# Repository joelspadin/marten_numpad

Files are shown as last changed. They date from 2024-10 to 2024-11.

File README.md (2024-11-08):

# Marten Numpad

Marten 22 is a wireless, 21/22 key numpad named after a [cute, woodland animal](https://en.wikipedia.org/wiki/American_marten). (There is no meaning to the name other than that I like them, and I couldn't find any existing keyboards named after them.) It is based on the nRF52840 SoC and uses a 3D printed case.

It has the following features:

- USB and Bluetooth support with [ZMK Firmware](https://zmk.dev/)
- Hot swap sockets for MX switches
- Supports Li-Ion or LiPo batteries up to 68x40x8 mm or 55x44x8 mm.
- The top-left and top-right keys can be replaced with encoders.
  - Supports [SKYLOONG keyboard knobs](https://skyloongtech.com/skyloong-keyboard-knobs/) (silicone/ABS cover versions only) or a separate encoder PCB with 3D printed case
- Any pair of two keys on the top row can be replaced with a display.
  - This uses a separate display PCB and connects with a ribbon cable.
  - nice!view and SSD1306 OLED display modules are supported.

A 22/23 key layout with a split plus key would be possible, but it would require a separate PCB from the 21/22 key layout. There is no way to fit three hot swap sockets into the space for the plus key without rotating the 1U keys 90 degrees, and this could damage keycaps, so I opted not to include that as an option.

(TODO: add renders/pictures of the completed keyboard)

> ⚠️ WARNING ⚠️ </br>
> I have received PCBs but they have not been fully tested. You should probably not make one yourself until I verify that everything works.

**Hardware status:**

| Component | Status |
| --- | --- |
| Numpad PCB | Untested |
| nice!view display module | Untested |
| OLED display module | Untested |
| Encoder module | Untested |
| 3D printed case | Untested |

**Firmware status:**

| Component | Status |
| --- | --- |
| Base firmware | Not implemented |
| Numlock LED | Not implemented |
| Custom display screen | Not implemented |
| nPM1300 charger | Not implemented |
| nPM1300 fuel gauge | Not implemented |
| Power button | Not implemented |

## PCB

KiCad files for the PCBs can be found in the [pcb](./pcb) directory. There are a few PCBs:

- [numpad.kicad_pro](./pcb/numpad.kicad_pro) is the main PCB.
- [display.kicad_pro](./pcb/display.kicad_pro) is an optional daughterboard for connecting a [nice!view](https://nicekeyboards.com/nice-view/) display.
- [display_oled.kicad_pro](./pcb/display_oled.kicad_pro) is an optional daughterboard for connect an SSD1306 OLED display.
  - It works with the common SSD1306 display modules you can find from a wide variety of sellers, but make sure to get one which does _not_ have a pin header already soldered.
- [encoder.kicad_pro](./pcb/encoder.kicad_pro) is an optional daughterboard for an EC11 encoder.
- [peripheral.kicad_pro](./pcb/peripheral.kicad_pro) is template for creating your own daughterboards.

The main PCB requires a couple of parts which are not hand solderable, so PCB assembly is required.

The display and encoder PCBs are hand solderable (though the SMD parts on the encoder are difficult to solder). The encoder PCB also requires modifying the EC11 encoder by clipping its pins short.

Instructions for ordering and assembling the hardware can be found on the wiki.

(TODO: add a wiki page)

[PCBWay](https://www.pcbway.com/) provided me a discount on PCB assembly in exchange for sharing pictures of the completed board and talking about my experience ordering from them. I will add details to the wiki for this once I've finished testing the hardware.

(TODO: add a wiki page)

### Custom Peripherals

The numpad PCB has a [Molex 5051100692](https://www.molex.com/en-us/products/part-detail/5051100692) FFC connector (labeled "Display") which can be used to connect to a daughterboard using a 6-pin ribbon cable. It provides 3.3 V power, two ground pins, and three GPIO pins. While its main purpose is to connect a display, you can use this to add your own custom hardware as well.

(TODO: add a wiki page explaining custom hardware and firmware)

## Case

TODO

## Firmware

TODO

## Credits

- Fonts:
  - [Fredoka](https://fonts.google.com/specimen/Fredoka)
- Libraries:
  - [marbastlib](https://github.com/ebastler/marbastlib)
  - Some footprints are modified from the [KiCad Libraries](https://gitlab.com/kicad/libraries/kicad-footprints)
- 3D models
  - Some 3D models are generated using [KiCad Packages3D Generator](https://gitlab.com/kicad/libraries/kicad-packages3D-generator)
  - [128x32 OLED display](https://grabcad.com/library/0-91-128x32-oled-display-1)
  - [JST SH connector](https://grabcad.com/library/jst-sh-smd-connectors-1)
  - Models for the following parts are provided by their respective manufacturers:
    - [Bourns PEC11L](https://www.bourns.com/products/encoders/contacting-encoders/product/PEC11L)
    - [HRO TYPE-C-31-M-12](https://www.snapeda.com/parts/TYPE-C-31-M-12/HRO%20Electronics%20Co.,%20Ltd./view-part/)
    - [Kingbright APTR3216-VFX](https://www.kingbrightusa.com/product.asp?catalog_name=LED&product_id=APTR3216-VFX)
    - [Molex 781710002](https://www.molex.com/en-us/products/part-detail/781710002)
    - [Molex 5051100692](https://www.molex.com/en-us/products/part-detail/5051100692)
    - [Mill-Max 811-22-002-30-004101](https://www.mill-max.com/products/spring-loaded/pogo-pin-header-strip/811/30-004101/811-22-002-30-004101)
    - [Mill-Max 811-22-004-30-001101](https://www.mill-max.com/products/spring-loaded/pogo-pin-header-strip/811/30-001101/811-22-004-30-001101)
    - [Mill-Max 821-22-005-10-001101](https://www.mill-max.com/products/spring-loaded/pogo-pin-header-strip/821/10-001101/821-22-005-10-001101)
    - [Raytac MDBT50Q-1MV2](https://www.raytac.com/product/ins.php?index_id=24)
    - [Würth 9774005243R](https://www.we-online.com/en/components/products/SMSI_SMT_STEEL_SPACER_M2_THREAD_INTERNAL)

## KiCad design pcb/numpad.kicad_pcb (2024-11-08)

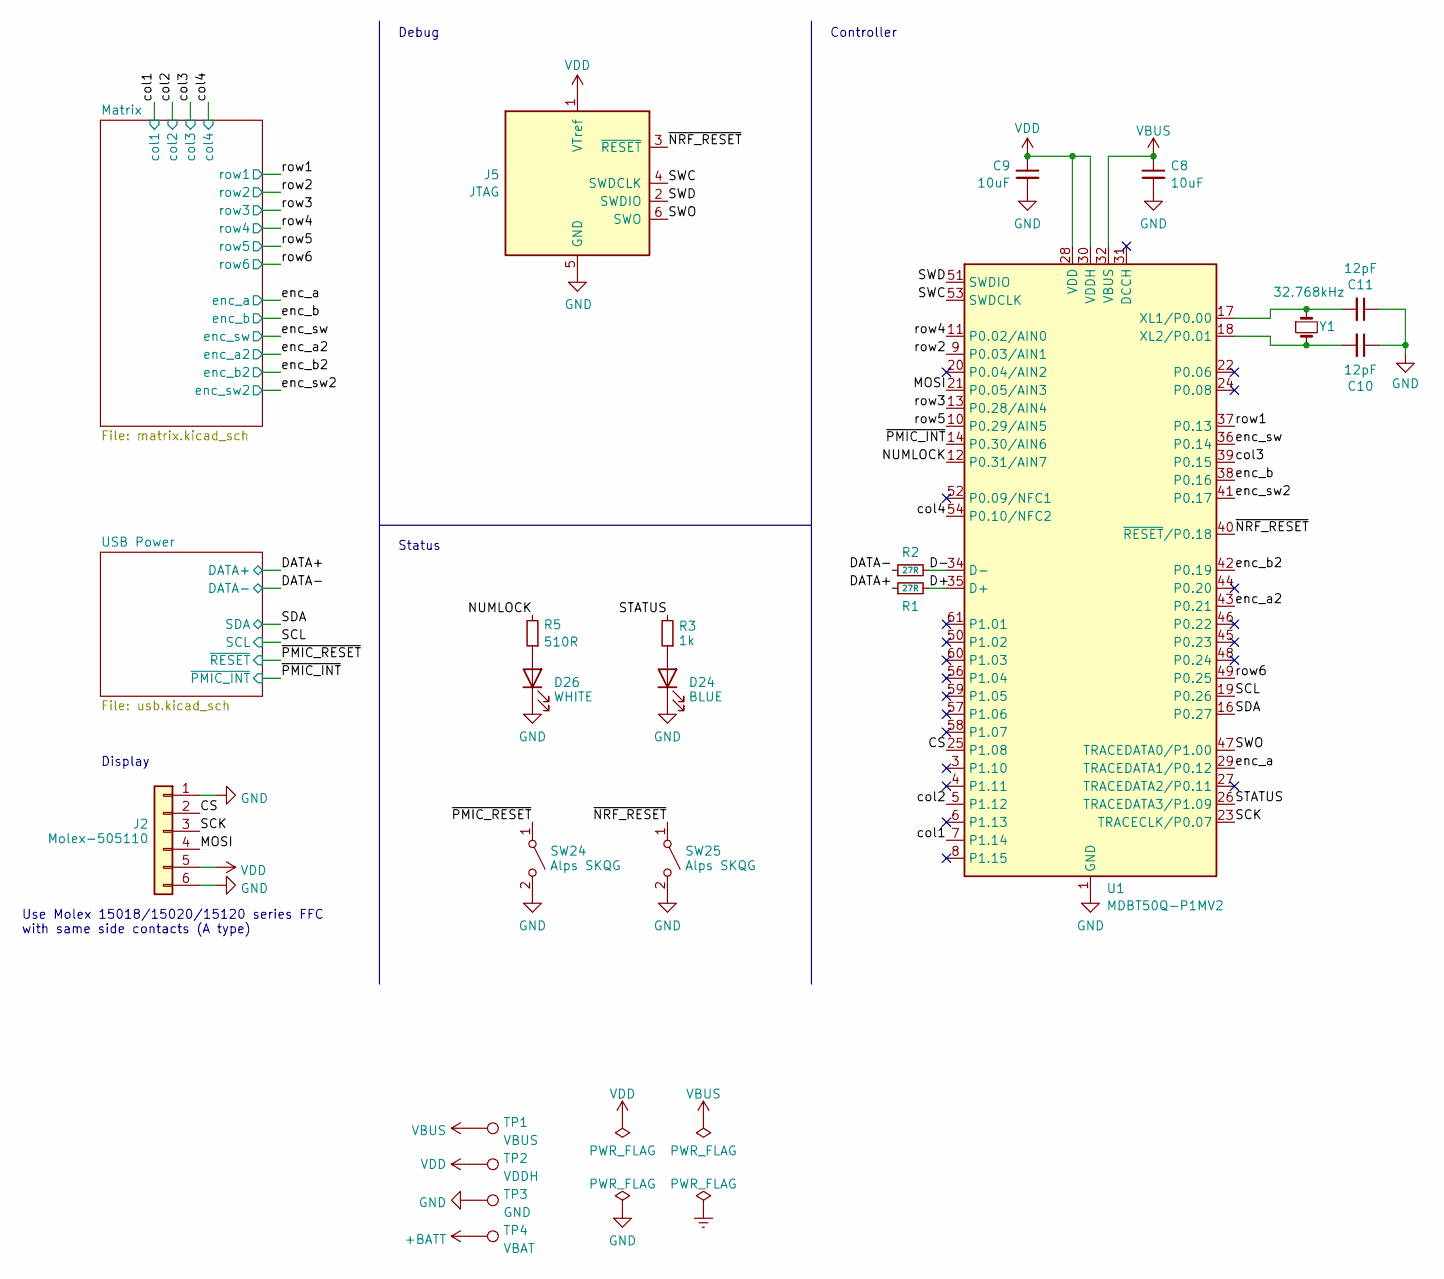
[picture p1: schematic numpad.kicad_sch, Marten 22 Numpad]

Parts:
C8, C9: 10uF; C_0603_1608Metric; Manufacturer Part Number GRM188Z71A106KA73D
C10, C11: 12pF; C_0402_1005Metric; Manufacturer Part Number CC0402GRNPO9BN120
D24: BLUE; LED_0603_1608Metric; Manufacturer Part Number NCD0603B5
D26: WHITE; LED_1206_3216Metric_ReverseMount_Hole2x2mm; Manufacturer Part Number MHT151WDT
J2: Molex-505110; Molex_5051100692_1x06_P0.5mm_Anchor; Manufacturer Part Number 5051100692
J5: JTAG; Tag-Connect_TC2030-IDC-NL_2x03_P1.27mm_Vertical; Manufacturer Part Number DNP
R1, R2: 27R; R_0402_1005Metric; Manufacturer Part Number RC0402FR-0727RL
R3: 1k; R_0603_1608Metric; Manufacturer Part Number FRC0603J102 TS
R5: 510R; R_0603_1608Metric; Manufacturer Part Number FRC0603J471 TS
SW24: Alps SKQG; SW_SPST_SKQG_WithStem; Manufacturer Part Number SKQGADE010
SW25: Alps SKQG; SW_SPST_SKQG_WithStem; Manufacturer Part Number SKQGABE010
TP1: VBUS; TestPoint_Pad_D1.5mm; Manufacturer Part Number DNP
TP2: VDDH; TestPoint_Pad_D1.5mm; Manufacturer Part Number DNP
TP3: GND; TestPoint_Pad_D1.5mm; Manufacturer Part Number DNP
TP4: VBAT; TestPoint_Pad_D1.5mm; Manufacturer Part Number DNP
U1: MDBT50Q-P1MV2; Raytac_MDBT50Q; Manufacturer Part Number MDBT50Q-P1MV2
Y1: 32.768kHz; Crystal_SMD_3215-2Pin_3.2x1.5mm; Manufacturer Part Number SC-32S32.768kHz20PPM9pF

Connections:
+BATT: TP4.1; also elsewhere on the board
/CS: J2.2, U1.25 (P1.08)
/D+: R1.2, U1.35 (D+)
/D-: R2.2, U1.34 (D-)
/DATA+: R1.1; also elsewhere on the board
/DATA-: R2.1; also elsewhere on the board
/MOSI: J2.4, U1.21 (P0.05/AIN3)
/NUMLOCK: R5.2, U1.12 (P0.31/AIN7)
/SCK: J2.3, U1.23 (TRACECLK/P0.07)
/SCL: U1.19 (P0.26); also elsewhere on the board
/SDA: U1.16 (P0.27); also elsewhere on the board
/STATUS: R3.2, U1.26 (TRACEDATA3/P1.09)
/SWC: J5.4 (SWDCLK), U1.53 (SWDCLK)
/SWD: J5.2 (SWDIO), U1.51 (SWDIO)
/SWO: J5.6 (SWO), U1.47 (TRACEDATA0/P1.00)
/col1: U1.7 (P1.14); also elsewhere on the board
/col2: U1.5 (P1.12); also elsewhere on the board
/col3: U1.39 (P0.15); also elsewhere on the board
/col4: U1.54 (P0.10/NFC2); also elsewhere on the board
/enc_a: U1.29 (TRACEDATA1/P0.12); also elsewhere on the board
/enc_a2: U1.43 (P0.21); also elsewhere on the board
/enc_b: U1.38 (P0.16); also elsewhere on the board
/enc_b2: U1.42 (P0.19); also elsewhere on the board
/enc_sw: U1.36 (P0.14); also elsewhere on the board
/enc_sw2: U1.41 (P0.17); also elsewhere on the board
/row1: U1.37 (P0.13); also elsewhere on the board
/row2: U1.9 (P0.03/AIN1); also elsewhere on the board
/row3: U1.13 (P0.28/AIN4); also elsewhere on the board
/row4: U1.11 (P0.02/AIN0); also elsewhere on the board
/row5: U1.10 (P0.29/AIN5); also elsewhere on the board
/row6: U1.49 (P0.25); also elsewhere on the board
/~NRF_RESET: J5.3 (~RESET), SW25.1 (A), U1.40 (~RESET/P0.18)
/~PMIC_INT: U1.14 (P0.30/AIN6); also elsewhere on the board
/~PMIC_RESET: SW24.1 (A); also elsewhere on the board
GND: C8.2, C9.2, C10.1, C11.1, D24.1 (K), D26.1 (K), J2.1, J2.6, J5.5 (GND), SW24.2 (B), SW25.2 (B), TP3.1, U1.1 (GND), U1.2 (GND), U1.15 (GND), U1.33 (GND), U1.55 (GND); also elsewhere on the board
unnamed: D24.2 (A), R3.1
unnamed: D26.2 (A), R5.1
unnamed: C11.2, U1.17 (XL1/P0.00), Y1.1
unnamed: C10.2, U1.18 (XL2/P0.01), Y1.2
VBUS: C8.1, TP1.1, U1.32 (VBUS); also elsewhere on the board
VDD: C9.1, J2.5, J5.1 (VTref), TP2.1, U1.28 (VDD), U1.30 (VDDH); also elsewhere on the board

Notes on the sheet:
Display
Controller
Debug
Use Molex 15018/15020/15120 series FFC with same side contacts (A type)
Status

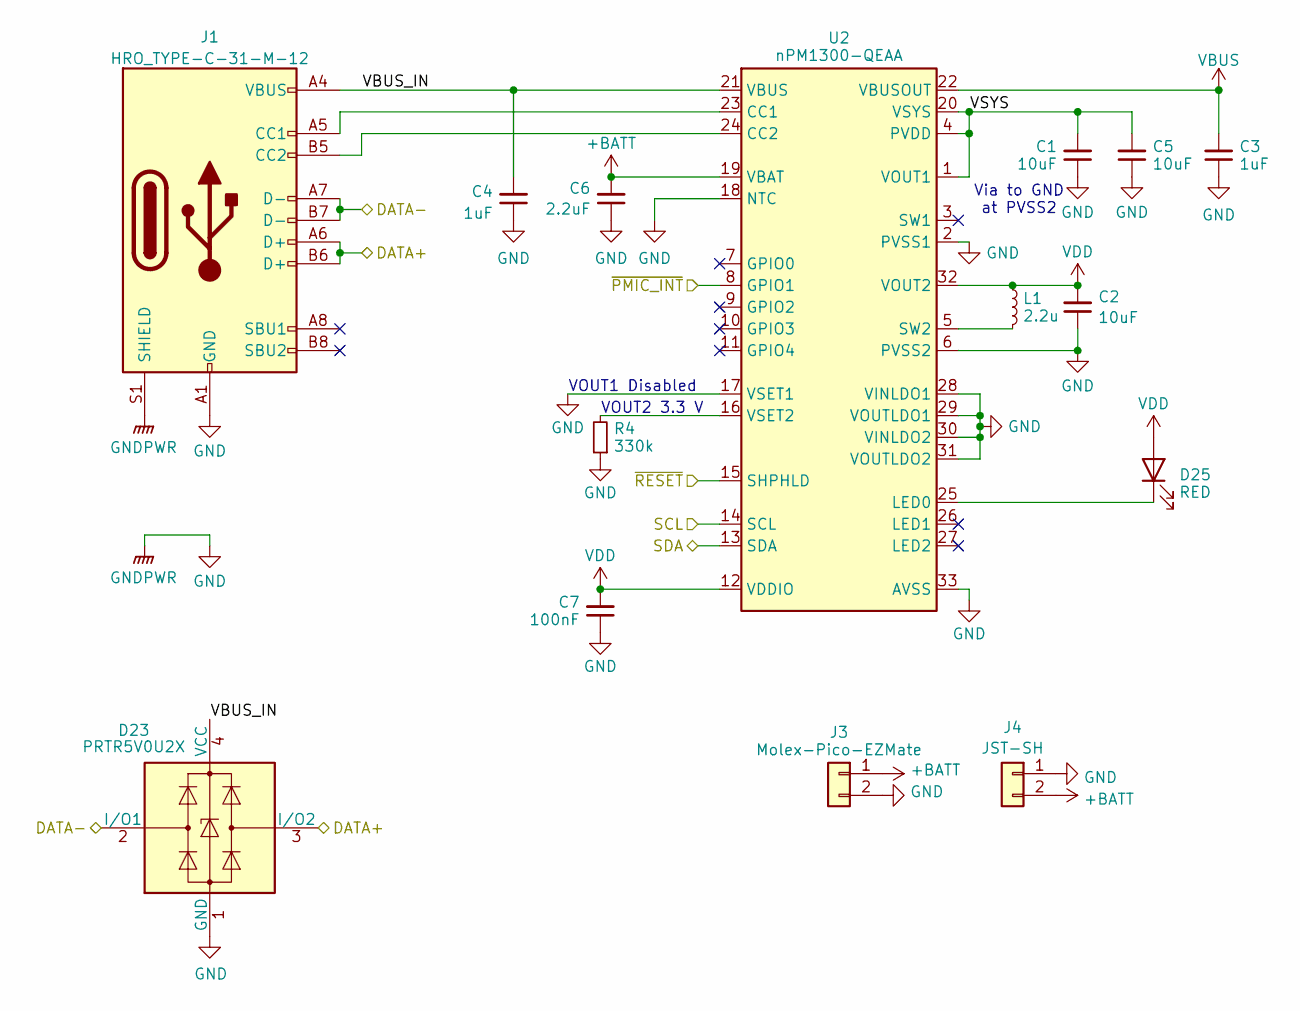
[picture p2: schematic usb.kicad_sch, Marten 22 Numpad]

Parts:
C1, C2, C5: 10uF; C_0603_1608Metric; Manufacturer Part Number 0603X106M250NT
C3, C4: 1uF; C_0603_1608Metric; Manufacturer Part Number 0603X105K100NT
C6: 2.2uF; C_0603_1608Metric; Manufacturer Part Number TCC0603X5R225K250CT
C7: 100nF; C_0402_1005Metric; Manufacturer Part Number TCC0402X5R104K250AT
D23: PRTR5V0U2X; SOT-143; Manufacturer Part Number PRTR5V0U2X,215
D25: RED; LED_0603_1608Metric; Manufacturer Part Number NCD0603R6
J1: HRO_TYPE-C-31-M-12; USB_C_Receptacle_HRO_TYPE-C-31-M-12; Manufacturer Part Number TYPE-C-31-M-12
J3: Molex-Pico-EZMate; Molex_Pico-EZmate_78171-0002_1x02-1MP_P1.20mm_Vertical; Manufacturer Part Number 781710002
J4: JST-SH; JST_SH_SM02B-SRSS-TB_1x02-1MP_P1.00mm_Horizontal_Anchor; Manufacturer Part Number SM02B-SRSS-TB
L1: 2.2u; L_0805_2012Metric; Manufacturer Part Number MLZ2012M2R2HT000
R4: 330k; R_0402_1005Metric; Manufacturer Part Number RC0402FR-07330KL
U2: nPM1300-QEAA; QFN-32-1EP_5x5mm_P0.5mm_EP3.5x3.5mm_ThermalVias; Manufacturer Part Number nPM1300-QEAA

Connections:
+BATT: C6.2, J3.1, J4.2, U2.19 (VBAT); also elsewhere on the board
/DATA+: D23.3 (I/O2), J1.A6 (D+), J1.B6 (D+); also elsewhere on the board
/DATA-: D23.2 (I/O1), J1.A7 (D-), J1.B7 (D-); also elsewhere on the board
/SCL: U2.14 (SCL); also elsewhere on the board
/SDA: U2.13 (SDA); also elsewhere on the board
/USB Power/VBUS_IN: C4.2, D23.4 (VCC), J1.A4 (VBUS), J1.A9 (VBUS), J1.B4 (VBUS), J1.B9 (VBUS), U2.21 (VBUS)
/USB Power/VSYS: C1.2, C5.2, U2.1 (VOUT1), U2.4 (PVDD), U2.20 (VSYS)
/~PMIC_INT: U2.8 (GPIO1); also elsewhere on the board
/~PMIC_RESET: U2.15 (SHPHLD); also elsewhere on the board
GND: C1.1, C2.1, C3.1, C4.1, C5.1, C6.1, C7.1, D23.1 (GND), J1.A1 (GND), J1.A12 (GND), J1.B1 (GND), J1.B12 (GND), J1.S1 (SHIELD), J3.2, J4.1, R4.1, U2.2 (PVSS1), U2.6 (PVSS2), U2.17 (VSET1), U2.18 (NTC), U2.28 (VINLDO1), U2.29 (VOUTLDO1), U2.30 (VINLDO2), U2.31 (VOUTLDO2), U2.33 (AVSS); also elsewhere on the board
unnamed: D25.1 (K), U2.25 (LED0)
unnamed: J1.A5 (CC1), U2.23 (CC1)
unnamed: J1.B5 (CC2), U2.24 (CC2)
unnamed: L1.2, U2.5 (SW2)
unnamed: R4.2, U2.16 (VSET2)
VBUS: C3.2, U2.22 (VBUSOUT); also elsewhere on the board
VDD: C2.2, C7.2, D25.2 (A), L1.1, U2.12 (VDDIO), U2.32 (VOUT2); also elsewhere on the board

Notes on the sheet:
VOUT1 Disabled
Via to GND at PVSS2
VOUT2 3.3 V

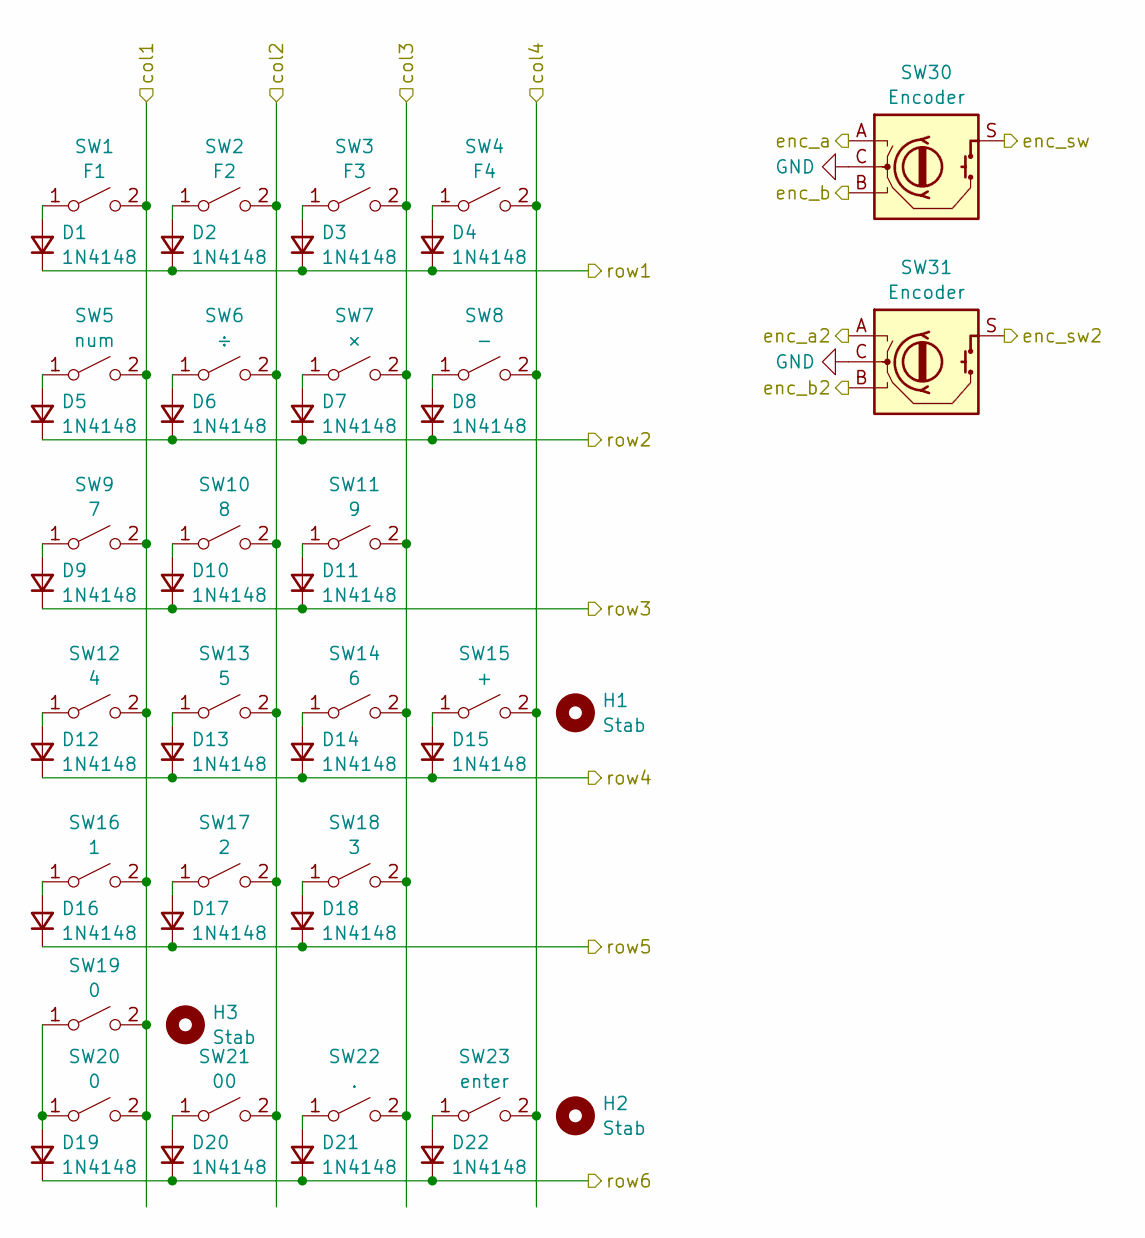
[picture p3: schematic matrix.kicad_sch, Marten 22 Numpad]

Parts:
D1, D2, D3, D4, D5, D6, D7, D8, D9, D10, D11, D12, D13, D14, D15, D16, D17, D18, D19, D20, D21, D22: 1N4148; D_SOD-523; Manufacturer Part Number 1N4148WT
H1, H2, H3: Stab; STAB_MX_2u; Manufacturer Part Number DNP
SW1: F1; SW_MX_HS_CPG151101S11_1u; Manufacturer Part Number CPG151101S11-16
SW2: F2; SW_MX_HS_CPG151101S11_1u; Manufacturer Part Number CPG151101S11-16
SW3: F3; SW_MX_HS_CPG151101S11_1u; Manufacturer Part Number CPG151101S11-16
SW4: F4; SW_MX_HS_CPG151101S11_1u; Manufacturer Part Number CPG151101S11-16
SW5: num; SW_MX_HS_CPG151101S11_1u; Manufacturer Part Number CPG151101S11-16
SW6: ÷; SW_MX_HS_CPG151101S11_1u; Manufacturer Part Number CPG151101S11-16
SW7: ×; SW_MX_HS_CPG151101S11_1u; Manufacturer Part Number CPG151101S11-16
SW8: −; SW_MX_HS_CPG151101S11_1u; Manufacturer Part Number CPG151101S11-16
SW9: 7; SW_MX_HS_CPG151101S11_1u; Manufacturer Part Number CPG151101S11-16
SW10: 8; SW_MX_HS_CPG151101S11_1u; Manufacturer Part Number CPG151101S11-16
SW11: 9; SW_MX_HS_CPG151101S11_1u; Manufacturer Part Number CPG151101S11-16
SW12: 4; SW_MX_HS_CPG151101S11_1u; Manufacturer Part Number CPG151101S11-16
SW13: 5; SW_MX_HS_CPG151101S11_1u; Manufacturer Part Number CPG151101S11-16
SW14: 6; SW_MX_HS_CPG151101S11_1u; Manufacturer Part Number CPG151101S11-16
SW15: +; SW_MX_HS_CPG151101S11_1u; Manufacturer Part Number CPG151101S11-16
SW16: 1; SW_MX_HS_CPG151101S11_1u; Manufacturer Part Number CPG151101S11-16
SW17: 2; SW_MX_HS_CPG151101S11_1u; Manufacturer Part Number CPG151101S11-16
SW18: 3; SW_MX_HS_CPG151101S11_1u; Manufacturer Part Number CPG151101S11-16
SW19, SW20: 0; SW_MX_HS_CPG151101S11_1u; Manufacturer Part Number CPG151101S11-16
SW21: 00; SW_MX_HS_CPG151101S11_1u; Manufacturer Part Number CPG151101S11-16
SW22: .; SW_MX_HS_CPG151101S11_1u; Manufacturer Part Number CPG151101S11-16
SW23: enter; SW_MX_HS_CPG151101S11_1u; Manufacturer Part Number CPG151101S11-16
SW30, SW31: Encoder; Skyloong_Knob_Pads; Manufacturer Part Number DNP

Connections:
/col1: SW1.2 (B), SW5.2 (B), SW9.2 (B), SW12.2 (B), SW16.2 (B), SW19.2 (B), SW20.2 (B); also elsewhere on the board
/col2: SW2.2 (B), SW6.2 (B), SW10.2 (B), SW13.2 (B), SW17.2 (B), SW21.2 (B); also elsewhere on the board
/col3: SW3.2 (B), SW7.2 (B), SW11.2 (B), SW14.2 (B), SW18.2 (B), SW22.2 (B); also elsewhere on the board
/col4: SW4.2 (B), SW8.2 (B), SW15.2 (B), SW23.2 (B); also elsewhere on the board
/enc_a: SW30.A; also elsewhere on the board
/enc_a2: SW31.A; also elsewhere on the board
/enc_b: SW30.B; also elsewhere on the board
/enc_b2: SW31.B; also elsewhere on the board
/enc_sw: SW30.S; also elsewhere on the board
/enc_sw2: SW31.S; also elsewhere on the board
/row1: D1.1 (K), D2.1 (K), D3.1 (K), D4.1 (K); also elsewhere on the board
/row2: D5.1 (K), D6.1 (K), D7.1 (K), D8.1 (K); also elsewhere on the board
/row3: D9.1 (K), D10.1 (K), D11.1 (K); also elsewhere on the board
/row4: D12.1 (K), D13.1 (K), D14.1 (K), D15.1 (K); also elsewhere on the board
/row5: D16.1 (K), D17.1 (K), D18.1 (K); also elsewhere on the board
/row6: D19.1 (K), D20.1 (K), D21.1 (K), D22.1 (K); also elsewhere on the board
GND: SW30.C, SW31.C; also elsewhere on the board
unnamed: D1.2 (A), SW1.1 (A)
unnamed: D2.2 (A), SW2.1 (A)
unnamed: D3.2 (A), SW3.1 (A)
unnamed: D4.2 (A), SW4.1 (A)
unnamed: D5.2 (A), SW5.1 (A)
unnamed: D6.2 (A), SW6.1 (A)
unnamed: D7.2 (A), SW7.1 (A)
unnamed: D8.2 (A), SW8.1 (A)
unnamed: D9.2 (A), SW9.1 (A)
unnamed: D10.2 (A), SW10.1 (A)
unnamed: D11.2 (A), SW11.1 (A)
unnamed: D12.2 (A), SW12.1 (A)
unnamed: D13.2 (A), SW13.1 (A)
unnamed: D14.2 (A), SW14.1 (A)
unnamed: D15.2 (A), SW15.1 (A)
unnamed: D16.2 (A), SW16.1 (A)
unnamed: D17.2 (A), SW17.1 (A)
unnamed: D18.2 (A), SW18.1 (A)
unnamed: D19.2 (A), SW19.1 (A), SW20.1 (A)
unnamed: D20.2 (A), SW21.1 (A)
unnamed: D21.2 (A), SW22.1 (A)
unnamed: D22.2 (A), SW23.1 (A)

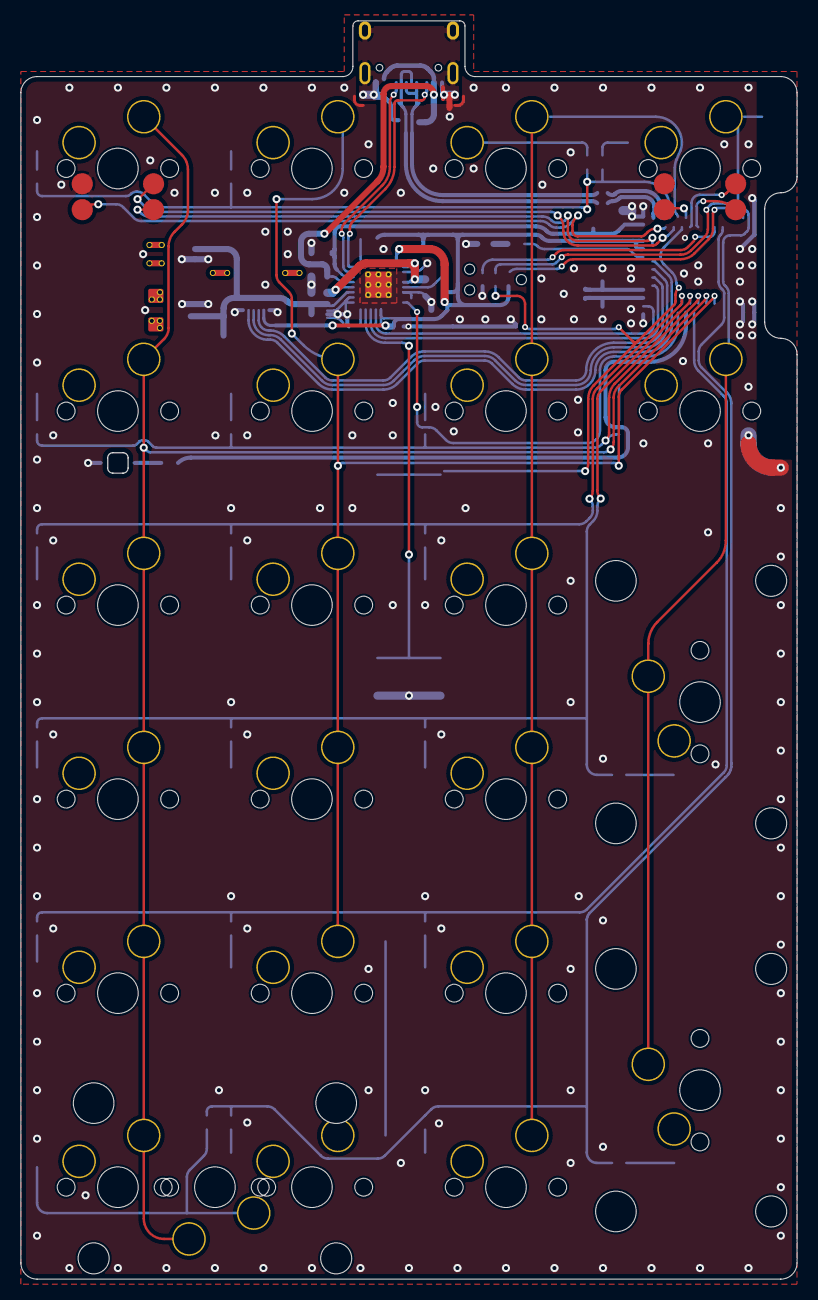
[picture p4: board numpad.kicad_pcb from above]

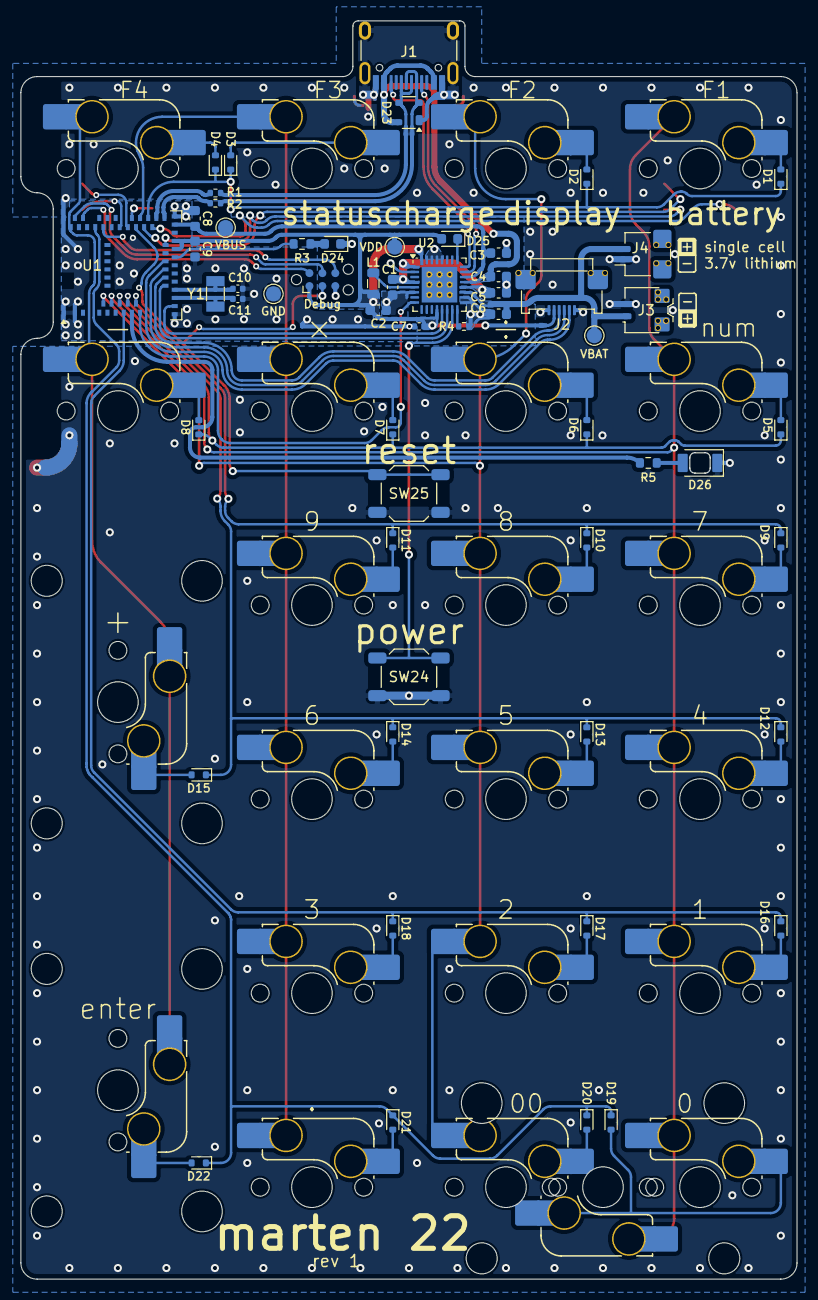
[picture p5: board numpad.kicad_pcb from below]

Board: 2 copper layers, 76.2 x 123.5 mm, 85 parts (81 on the bottom side), 70 nets.

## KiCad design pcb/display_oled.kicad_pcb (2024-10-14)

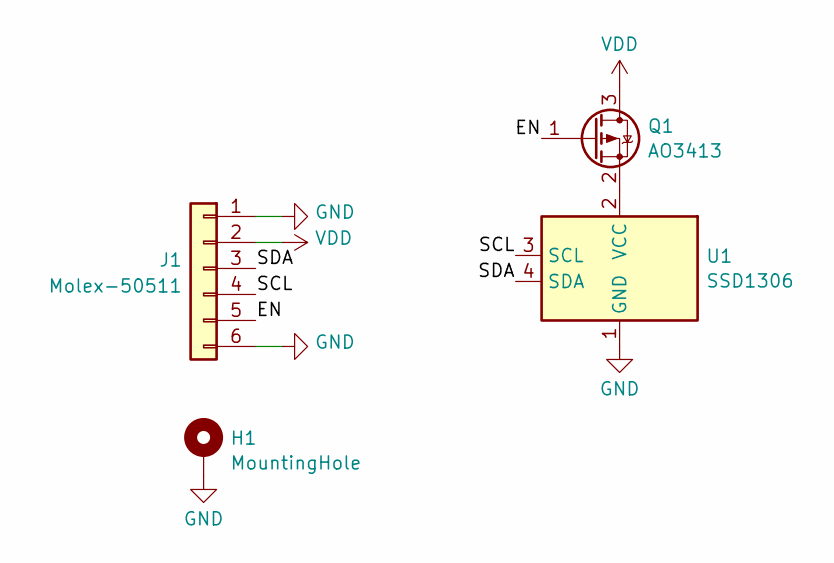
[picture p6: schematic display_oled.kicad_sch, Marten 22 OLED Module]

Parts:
H1: MountingHole; MountingHole_2.2mm_M2_Pad_Via; Manufacturer Part Number DNP
J1: Molex-50511; Molex_5051100692_1x06_P0.5mm_Anchor_2; Manufacturer Part Number 5051100692
Q1: AO3413; SOT-23-3
U1: SSD1306; SSD1306_Pogo_Pin; Manufacturer Part Number 821-22-005-10-000101

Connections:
/EN: J1.5, Q1.1 (G)
/SCL: J1.4, U1.3 (SCL)
/SDA: J1.3, U1.4 (SDA)
GND: H1.1, J1.1, J1.6, U1.1 (GND)
unnamed: Q1.2 (S), U1.2 (VCC)
VDD: J1.2, Q1.3 (D)

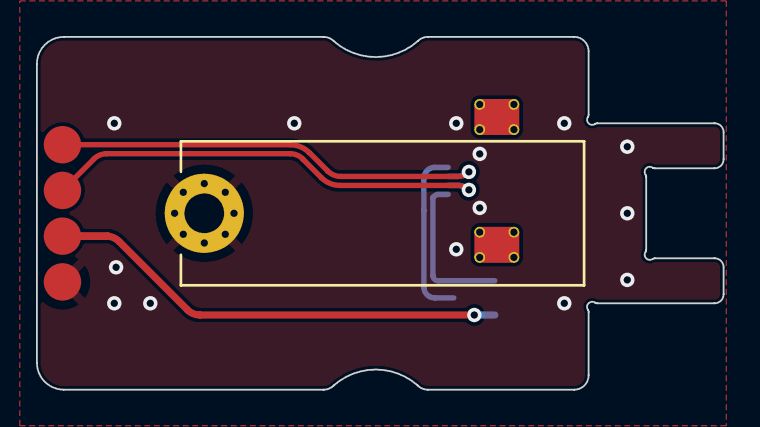
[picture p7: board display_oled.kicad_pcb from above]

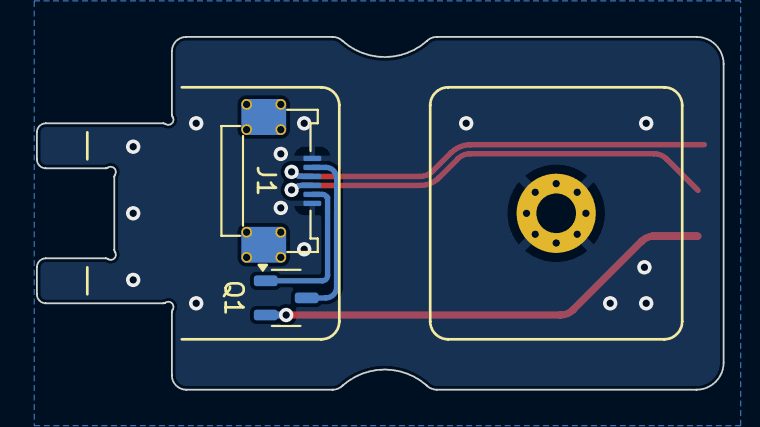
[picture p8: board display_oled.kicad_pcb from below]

Board: 2 copper layers, 38.1 x 19.6 mm, 4 parts (2 on the bottom side), 6 nets.

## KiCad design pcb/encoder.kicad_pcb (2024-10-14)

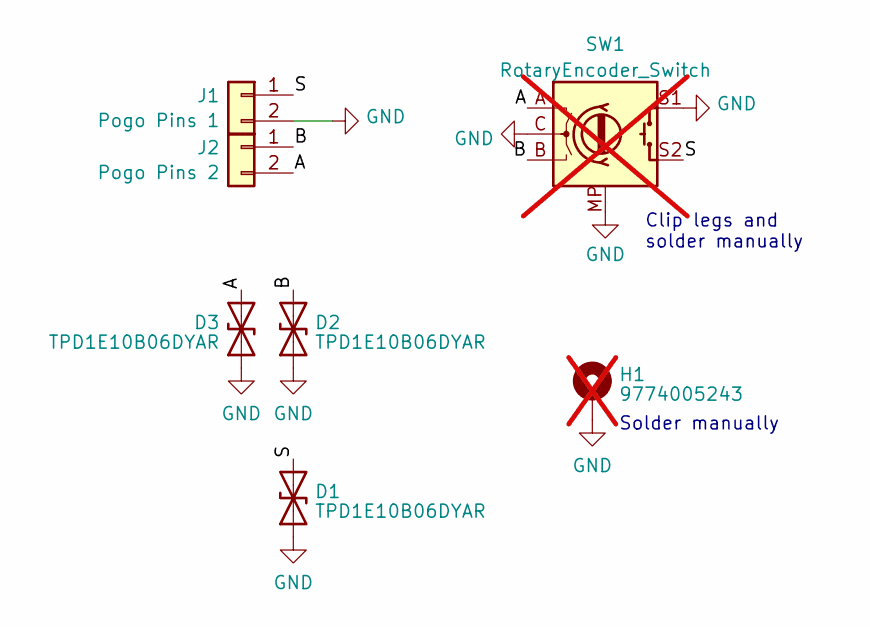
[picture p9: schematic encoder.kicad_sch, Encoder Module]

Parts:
D1, D2, D3: TPD1E10B06DYAR; D_SOD-523; Manufacturer Part Number TPD1E10B06DYAR
H1: 9774005243; Wurth_9774005243; Manufacturer Part Number 9774005243R; not fitted
J1: Pogo Pins 1; Mill-Max_811-22-002-03-004101; Manufacturer Part Number 811-22-002-30-004101
J2: Pogo Pins 2; Mill-Max_811-22-002-03-004101; Manufacturer Part Number 811-22-002-30-004101
SW1: RotaryEncoder_Switch; Bourns_PEC11L-Switch; Manufacturer Part Number PEC11L-4115F-S0020; not fitted

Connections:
/A: D3.2 (A2), J2.2, SW1.A
/B: D2.2 (A2), J2.1, SW1.B
/S: D1.2 (A2), J1.1, SW1.S2
GND: D1.1 (A1), D2.1 (A1), D3.1 (A1), H1.1, J1.2, SW1.C, SW1.MP, SW1.S1

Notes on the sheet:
Solder manually
Clip legs and solder manually

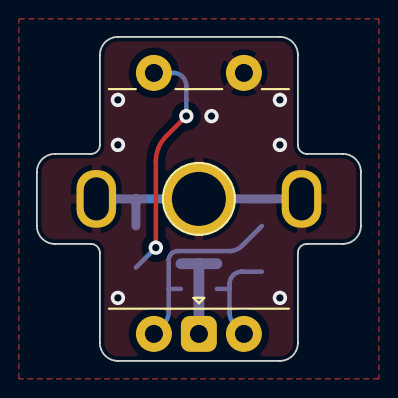
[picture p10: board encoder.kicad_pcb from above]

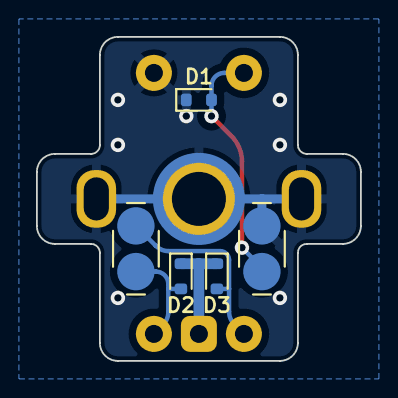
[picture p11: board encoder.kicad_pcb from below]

Board: 2 copper layers, 18.0 x 18.0 mm, 7 parts (6 on the bottom side), 4 nets.

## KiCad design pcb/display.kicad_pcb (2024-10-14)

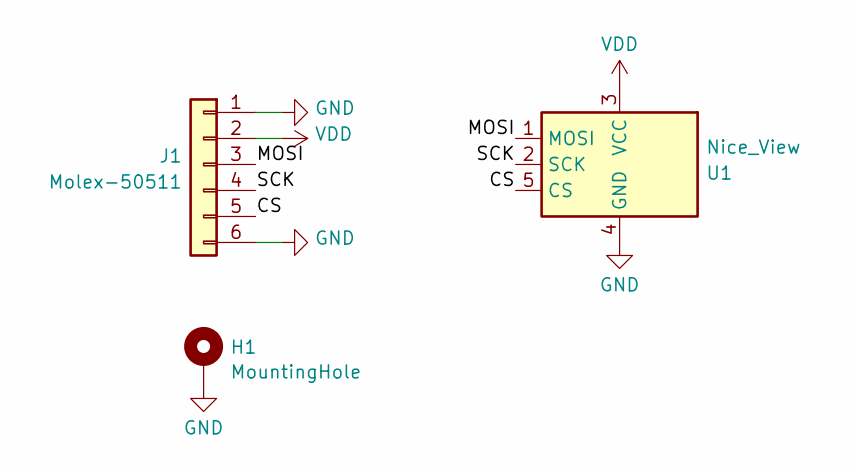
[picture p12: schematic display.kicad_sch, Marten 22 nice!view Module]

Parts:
H1: MountingHole; MountingHole_2.2mm_M2_Pad_Via; Manufacturer Part Number DNP
J1: Molex-50511; Molex_5051100692_1x06_P0.5mm_Anchor_2; Manufacturer Part Number 505110069
U1: Nice_View; Nice_View_Pogo_pin; Manufacturer Part Number 821-22-005-10-000101

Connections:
/CS: J1.5, U1.5 (CS)
/MOSI: J1.3, U1.1 (MOSI)
/SCK: J1.4, U1.2 (SCK)
GND: H1.1, J1.1, J1.6, U1.4 (GND)
VDD: J1.2, U1.3 (VCC)


Board: 2 copper layers, 37.8 x 19.6 mm, 3 parts (1 on the bottom side), 5 nets.

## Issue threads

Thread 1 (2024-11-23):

Potential improvements

joelspadin, 2024-11-23:
Ideas for a rev 2:

- Add ESD protection for CC lines.
- Add a resettable fuse on VBUS? nPM1300 can withstand 22 V for short periods but not for an extended time.
- Choose a different switch for reset/power that's easier to press.

joelspadin, 2025-08-26:
The charge LED is *very* bright. Either find a dimmer LED, or add a resistor, since the npm1300 doesn't have brightness control with its LEDs.

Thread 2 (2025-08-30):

Too much solder on npm1300

joelspadin, 2025-08-30:
Of the five boards I ordered, three had large blobs of solder on some pins of the npm1300, and one of those had a blob bridging two pins. I likely need to shrink the paste areas to reduce the amount of solder applied.

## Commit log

2024-10-14 Reorganize repo and start clean history
    Restarting the history of the repo to avoid bloating it with old fonts
    and 3D models that I ended up not using.
    [display.kicad_pcb, display.kicad_sch, display_oled.kicad_pcb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]
2024-10-14 Use KiCad SOT-23-3 footprint
    The copied footprint was likely due to a missing 3D model, but the
    current KiCad library has a 3D model now.
    [display_oled.kicad_pcb, display_oled.kicad_sch]
2024-11-03 Fix BOM and update DRC exclusions
    [numpad.kicad_pcb, numpad.kicad_sch]
2024-11-08 Add Molex connector to peripheral template
    [peripheral.kicad_pcb, peripheral.kicad_sch]
2024-11-08 Use switch requiring less force for reset/power
    [numpad.kicad_pcb, numpad.kicad_sch]
